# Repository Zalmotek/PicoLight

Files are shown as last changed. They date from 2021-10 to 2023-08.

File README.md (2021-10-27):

# PicoLight 🌈

✨ PicoLight is a minimalist adjustable light for low-light photography, based on the Raspberry Pi Pico.

✨ For more details check out the project documentation on [Hackaday](https://hackaday.io/project/182069-picolight-minimalist-light-for-product-shots).

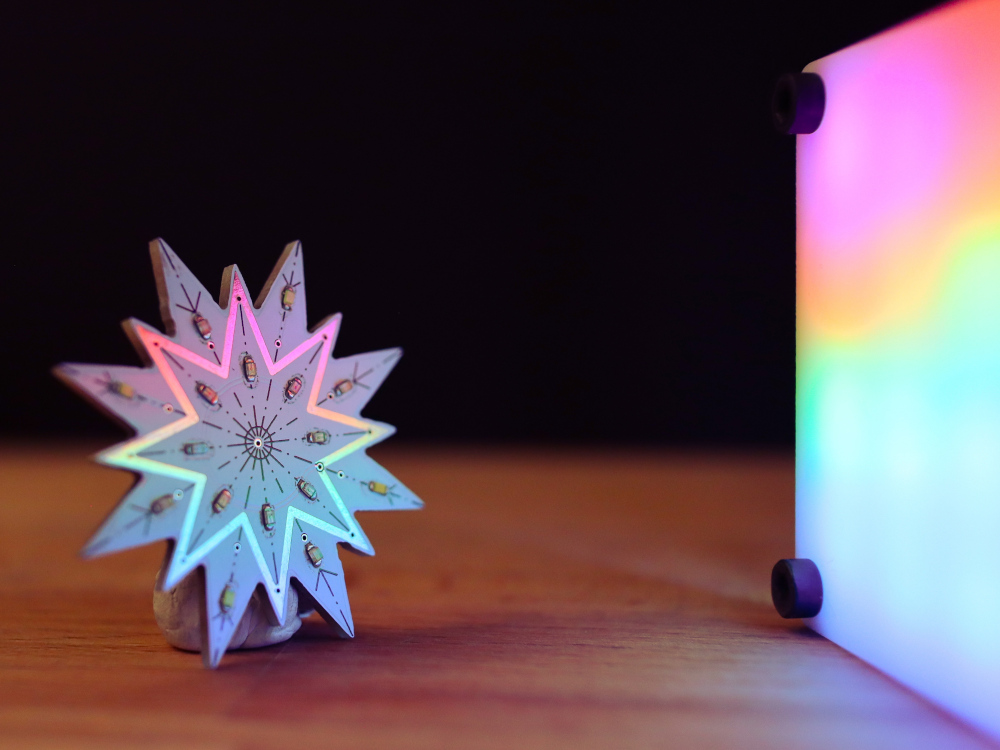
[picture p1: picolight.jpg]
PicoLight


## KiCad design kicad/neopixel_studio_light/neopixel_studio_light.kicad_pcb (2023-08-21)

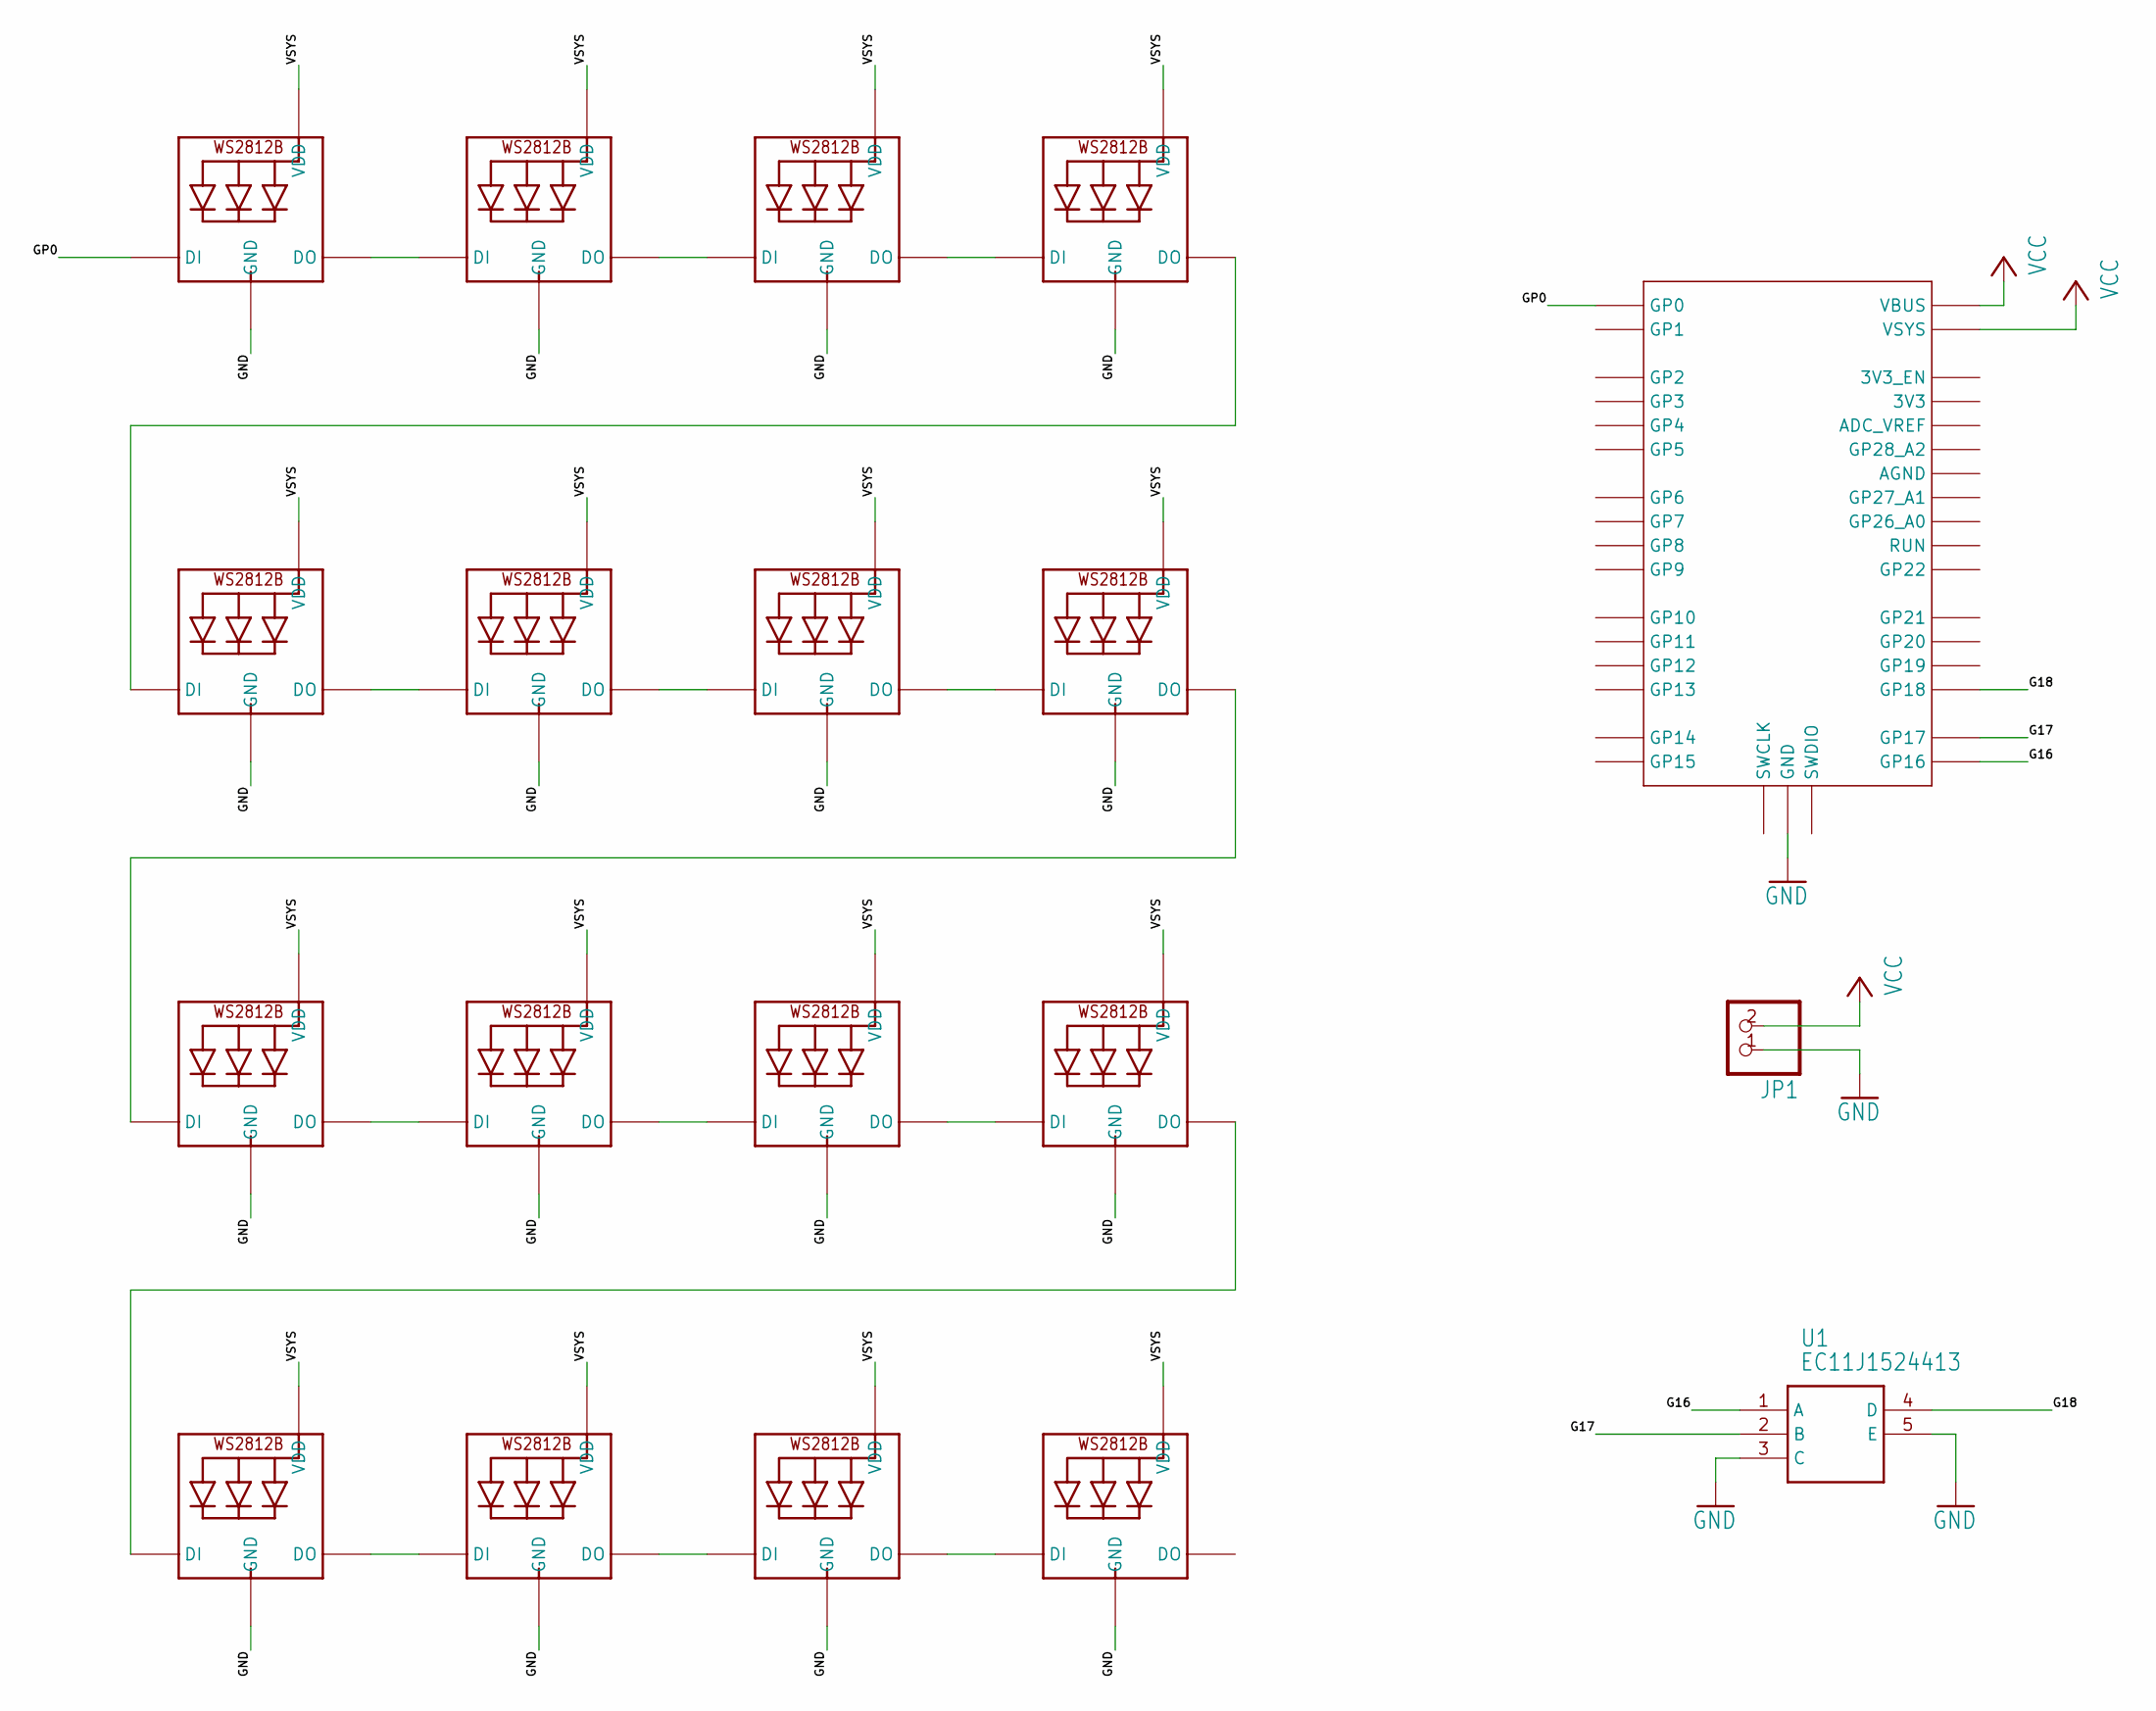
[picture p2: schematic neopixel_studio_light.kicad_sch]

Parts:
JP1: PINHD-1X2; 1X02
LED1, LED2, LED3, LED4, LED5, LED6, LED7, LED8, LED9, LED10, LED11, LED12, LED13, LED14, LED15, LED16: WS2812B5050; WS2812B
U1: EC11J1524413
U$1: RPI_PICO-SMD; RPI_PICO

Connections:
/G16: U1.1 (A), U$1.GP16
/G17: U1.2 (B), U$1.GP17
/G18: U1.4 (D), U$1.GP18
/GP0: LED1.4-DIN (DI), U$1.GP0
/VSYS: LED1.1-VDD (VDD), LED2.1-VDD (VDD), LED3.1-VDD (VDD), LED4.1-VDD (VDD), LED5.1-VDD (VDD), LED6.1-VDD (VDD), LED7.1-VDD (VDD), LED8.1-VDD (VDD), LED9.1-VDD (VDD), LED10.1-VDD (VDD), LED11.1-VDD (VDD), LED12.1-VDD (VDD), LED13.1-VDD (VDD), LED14.1-VDD (VDD), LED15.1-VDD (VDD), LED16.1-VDD (VDD)
GND: JP1.1, LED1.3-GND (GND), LED2.3-GND (GND), LED3.3-GND (GND), LED4.3-GND (GND), LED5.3-GND (GND), LED6.3-GND (GND), LED7.3-GND (GND), LED8.3-GND (GND), LED9.3-GND (GND), LED10.3-GND (GND), LED11.3-GND (GND), LED12.3-GND (GND), LED13.3-GND (GND), LED14.3-GND (GND), LED15.3-GND (GND), LED16.3-GND (GND), U1.3 (C), U1.5 (E), U$1.GND@1 (GND), U$1.GND@2 (GND), U$1.GND@3 (GND), U$1.GND@4 (GND), U$1.GND@5 (GND), U$1.GND@6 (GND), U$1.GND@7 (GND), U$1.GND@8 (GND)
unnamed: LED1.2-DOUT (DO), LED2.4-DIN (DI)
unnamed: LED2.2-DOUT (DO), LED3.4-DIN (DI)
unnamed: LED3.2-DOUT (DO), LED4.4-DIN (DI)
unnamed: LED4.2-DOUT (DO), LED5.4-DIN (DI)
unnamed: LED5.2-DOUT (DO), LED6.4-DIN (DI)
unnamed: LED6.2-DOUT (DO), LED7.4-DIN (DI)
unnamed: LED7.2-DOUT (DO), LED8.4-DIN (DI)
unnamed: LED8.2-DOUT (DO), LED9.4-DIN (DI)
unnamed: LED9.2-DOUT (DO), LED10.4-DIN (DI)
unnamed: LED10.2-DOUT (DO), LED11.4-DIN (DI)
unnamed: LED11.2-DOUT (DO), LED12.4-DIN (DI)
unnamed: LED12.2-DOUT (DO), LED13.4-DIN (DI)
unnamed: LED13.2-DOUT (DO), LED14.4-DIN (DI)
unnamed: LED14.2-DOUT (DO), LED15.4-DIN (DI)
unnamed: LED15.2-DOUT (DO), LED16.4-DIN (DI)
VCC: JP1.2, U$1.VBUS, U$1.VSYS

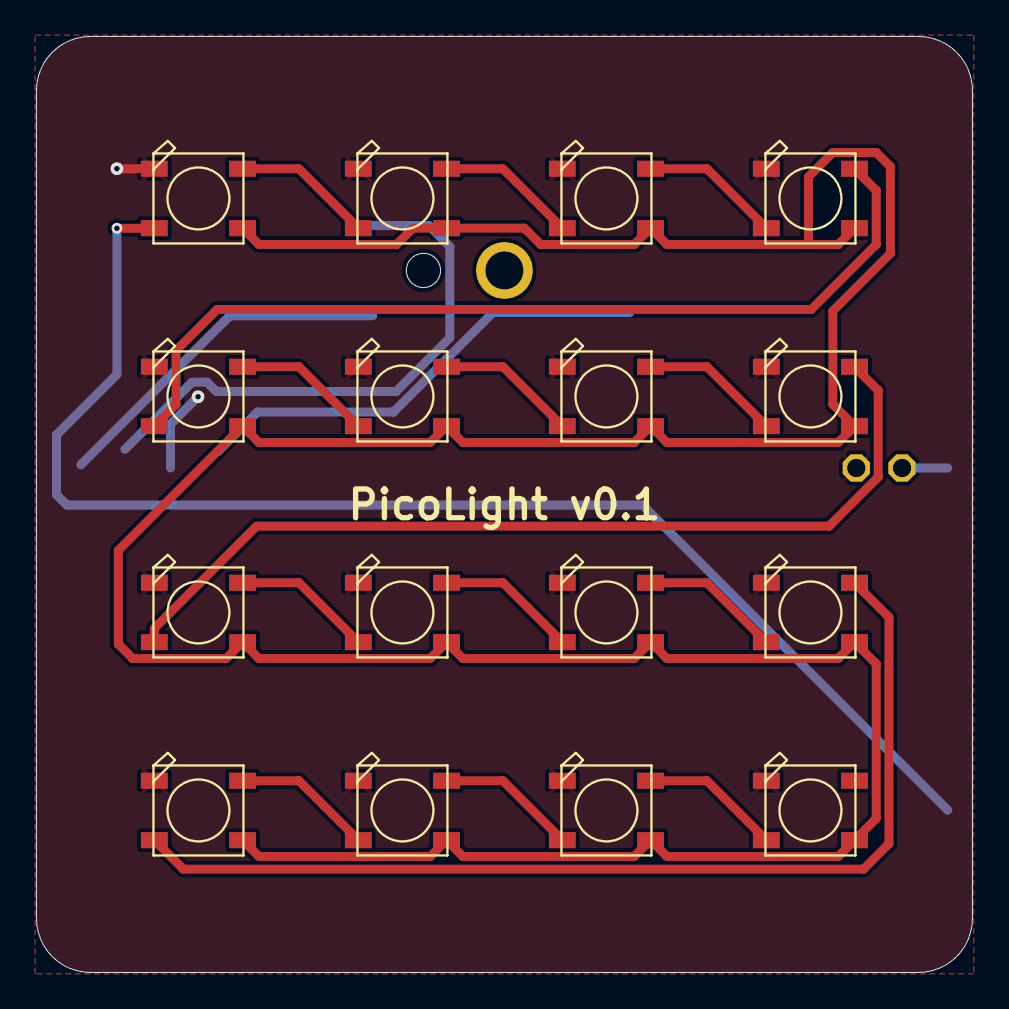
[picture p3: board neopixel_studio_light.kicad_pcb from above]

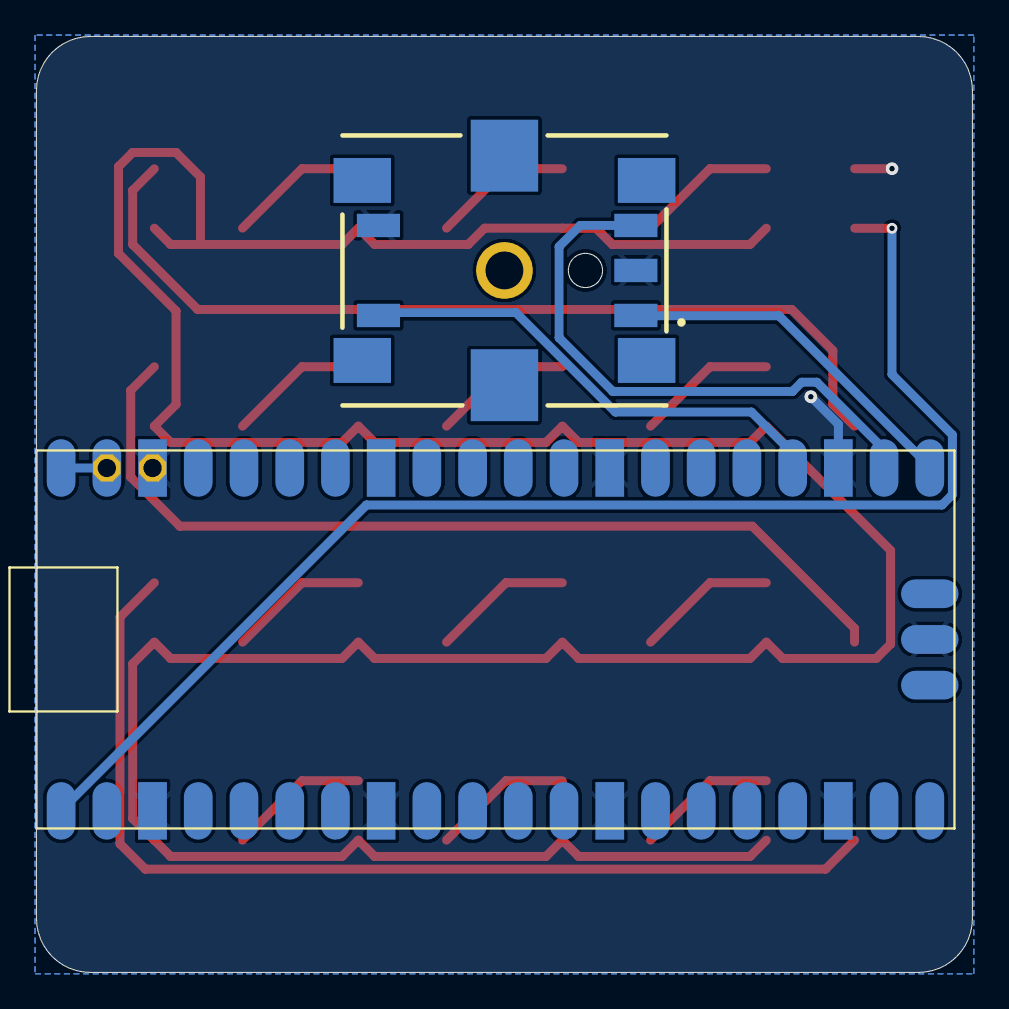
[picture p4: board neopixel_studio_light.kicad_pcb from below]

Board: 2 copper layers, 52.0 x 52.0 mm, 19 parts (2 on the bottom side), 22 nets.

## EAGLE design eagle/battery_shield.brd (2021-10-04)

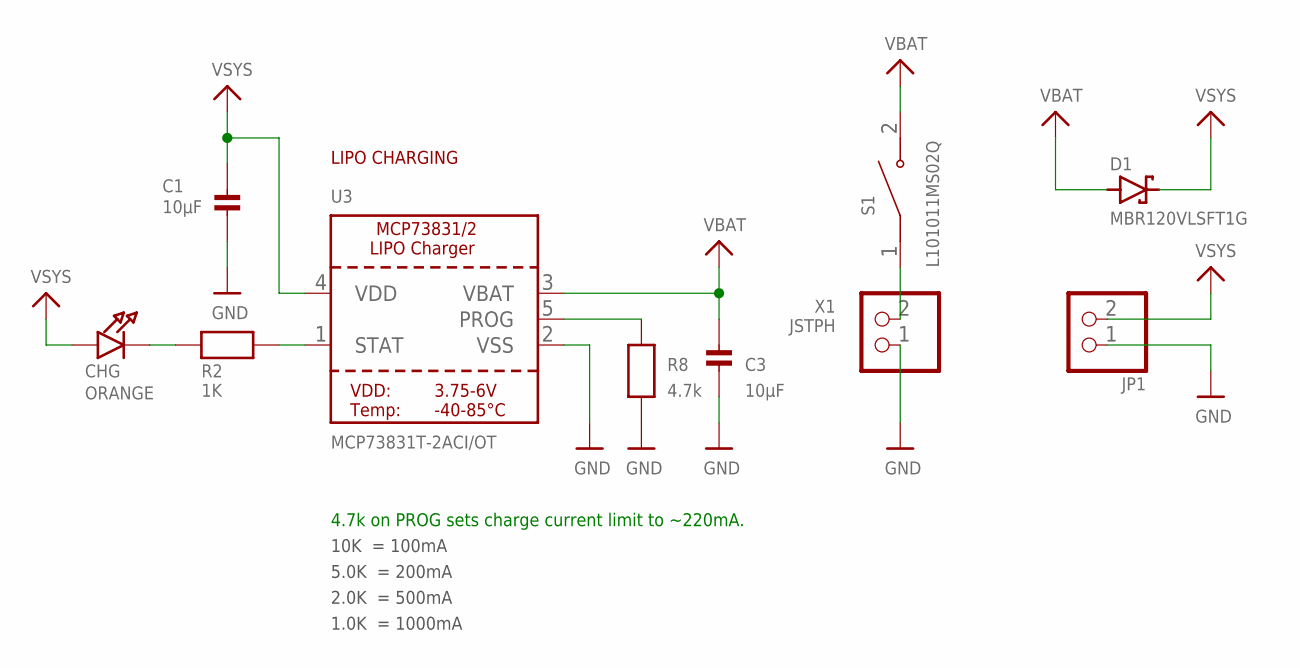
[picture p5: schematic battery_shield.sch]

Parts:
C1, C3: 10µF; 0805-NO
CHG: ORANGE; CHIPLED_0805_NOOUTLINE
D1: MBR120VLSFT1G; SOD123FL
JP1: PINHD-1X2; 1X02
R2: 1K; 0603-NO
R8: 4.7k; 0603-NO
S1: L101011MS02Q; SW_L101011MS02Q
U3: MCP73831T-2ACI/OT; SOT23-5
X1: JSTPH; JSTPH2

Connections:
GND: C1.2, C3.2, JP1.1, R8.2, U3.2 (VSS), X1.1
unnamed: CHG.C, R2.1
unnamed: S1.1, X1.2
unnamed: R2.2, U3.1 (STAT)
unnamed: R8.1, U3.5 (PROG)
VBAT: C3.1, D1.A, S1.2, U3.3 (VBAT)
VSYS: C1.1, CHG.A, D1.C, JP1.2, U3.4 (VDD)

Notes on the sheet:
10K = 100mA
5.0K = 200mA
2.0K = 500mA
1.0K = 1000mA
LIPO CHARGING
4.7k on PROG sets charge current limit to ~220mA.

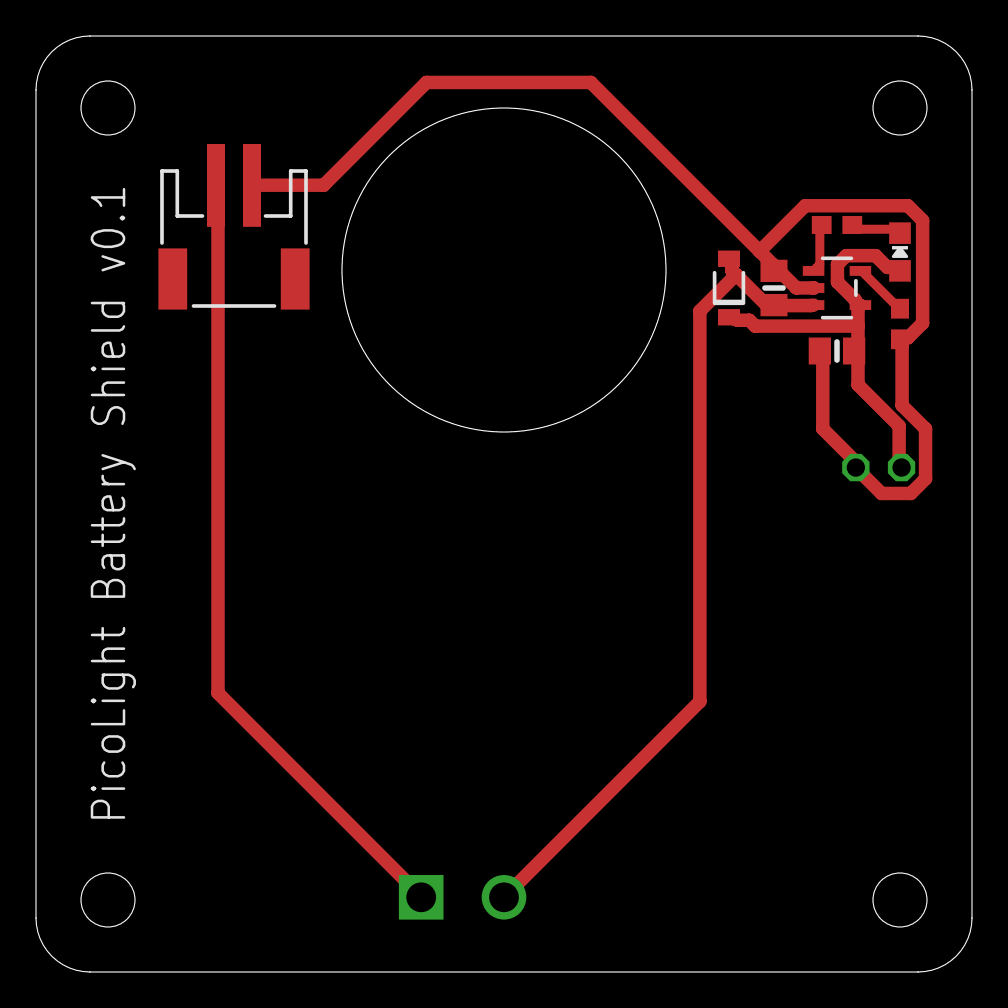
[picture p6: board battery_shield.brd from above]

Board: 2 copper layers, 52.0 x 52.0 mm, 10 parts (1 on the bottom side), 7 nets.

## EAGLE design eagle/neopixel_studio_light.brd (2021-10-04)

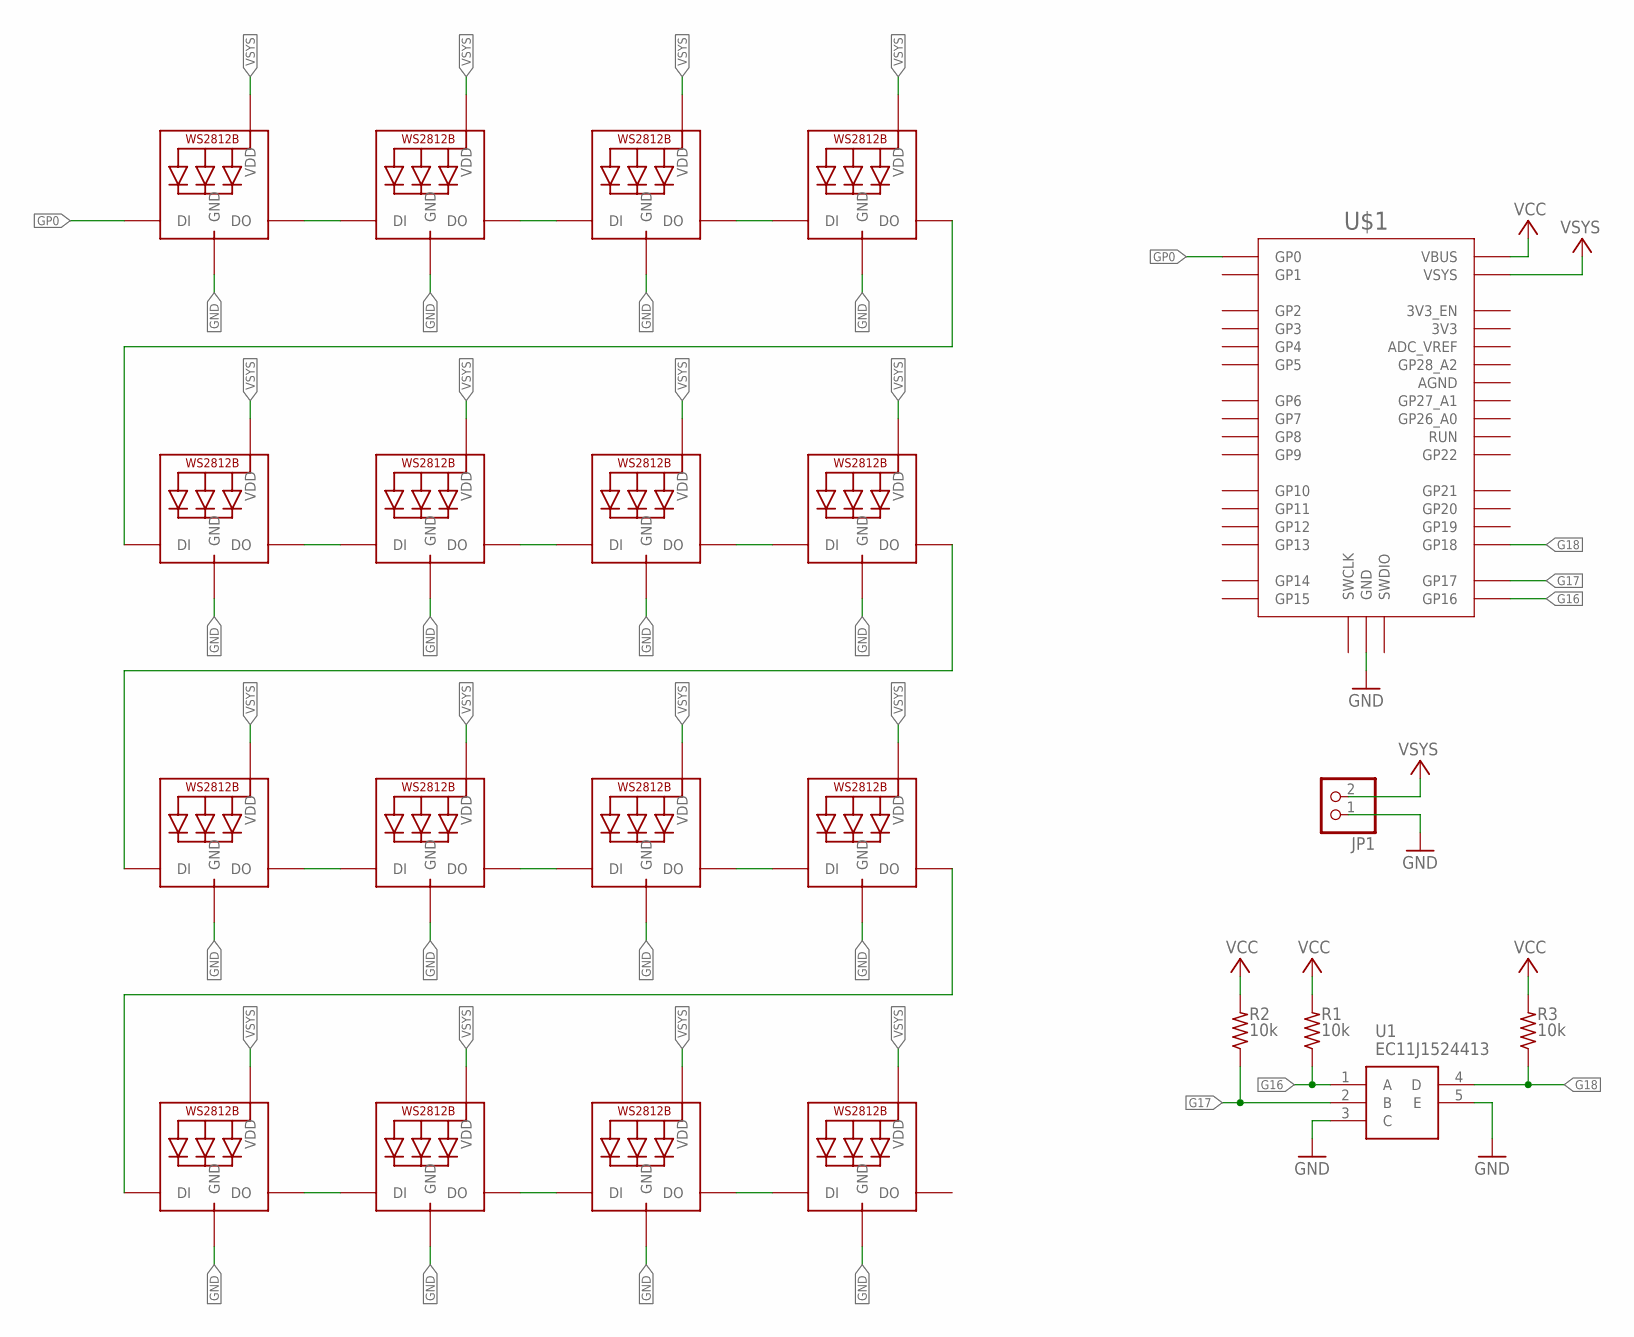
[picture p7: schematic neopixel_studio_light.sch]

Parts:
JP1: PINHD-1X2; 1X02
LED1, LED2, LED3, LED4, LED5, LED6, LED7, LED8, LED9, LED10, LED11, LED12, LED13, LED14, LED15, LED16: WS2812B5050; WS2812B
R1, R2, R3: 10k; R0603
U1: EC11J1524413
U$1: RPI_PICO-SMD; RPI_PICO

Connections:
G16: R1.1, U1.1 (A), U$1.GP16
G17: R2.1, U1.2 (B), U$1.GP17
G18: R3.1, U1.4 (D), U$1.GP18
GND: JP1.1, LED1.3-GND (GND), LED2.3-GND (GND), LED3.3-GND (GND), LED4.3-GND (GND), LED5.3-GND (GND), LED6.3-GND (GND), LED7.3-GND (GND), LED8.3-GND (GND), LED9.3-GND (GND), LED10.3-GND (GND), LED11.3-GND (GND), LED12.3-GND (GND), LED13.3-GND (GND), LED14.3-GND (GND), LED15.3-GND (GND), LED16.3-GND (GND), U1.3 (C), U1.5 (E), U$1.GND@1 (GND), U$1.GND@2 (GND), U$1.GND@3 (GND), U$1.GND@4 (GND), U$1.GND@5 (GND), U$1.GND@6 (GND), U$1.GND@7 (GND), U$1.GND@8 (GND)
GP0: LED1.4-DIN (DI), U$1.GP0
unnamed: LED1.2-DOUT (DO), LED2.4-DIN (DI)
unnamed: LED2.2-DOUT (DO), LED3.4-DIN (DI)
unnamed: LED3.2-DOUT (DO), LED4.4-DIN (DI)
unnamed: LED4.2-DOUT (DO), LED5.4-DIN (DI)
unnamed: LED5.2-DOUT (DO), LED6.4-DIN (DI)
unnamed: LED6.2-DOUT (DO), LED7.4-DIN (DI)
unnamed: LED7.2-DOUT (DO), LED8.4-DIN (DI)
unnamed: LED8.2-DOUT (DO), LED9.4-DIN (DI)
unnamed: LED12.2-DOUT (DO), LED13.4-DIN (DI)
unnamed: LED13.2-DOUT (DO), LED14.4-DIN (DI)
unnamed: LED14.2-DOUT (DO), LED15.4-DIN (DI)
unnamed: LED15.2-DOUT (DO), LED16.4-DIN (DI)
unnamed: LED9.2-DOUT (DO), LED10.4-DIN (DI)
unnamed: LED10.2-DOUT (DO), LED11.4-DIN (DI)
unnamed: LED11.2-DOUT (DO), LED12.4-DIN (DI)
VCC: R1.2, R2.2, R3.2, U$1.VBUS
VSYS: JP1.2, LED1.1-VDD (VDD), LED2.1-VDD (VDD), LED3.1-VDD (VDD), LED4.1-VDD (VDD), LED5.1-VDD (VDD), LED6.1-VDD (VDD), LED7.1-VDD (VDD), LED8.1-VDD (VDD), LED9.1-VDD (VDD), LED10.1-VDD (VDD), LED11.1-VDD (VDD), LED12.1-VDD (VDD), LED13.1-VDD (VDD), LED14.1-VDD (VDD), LED15.1-VDD (VDD), LED16.1-VDD (VDD), U$1.VSYS

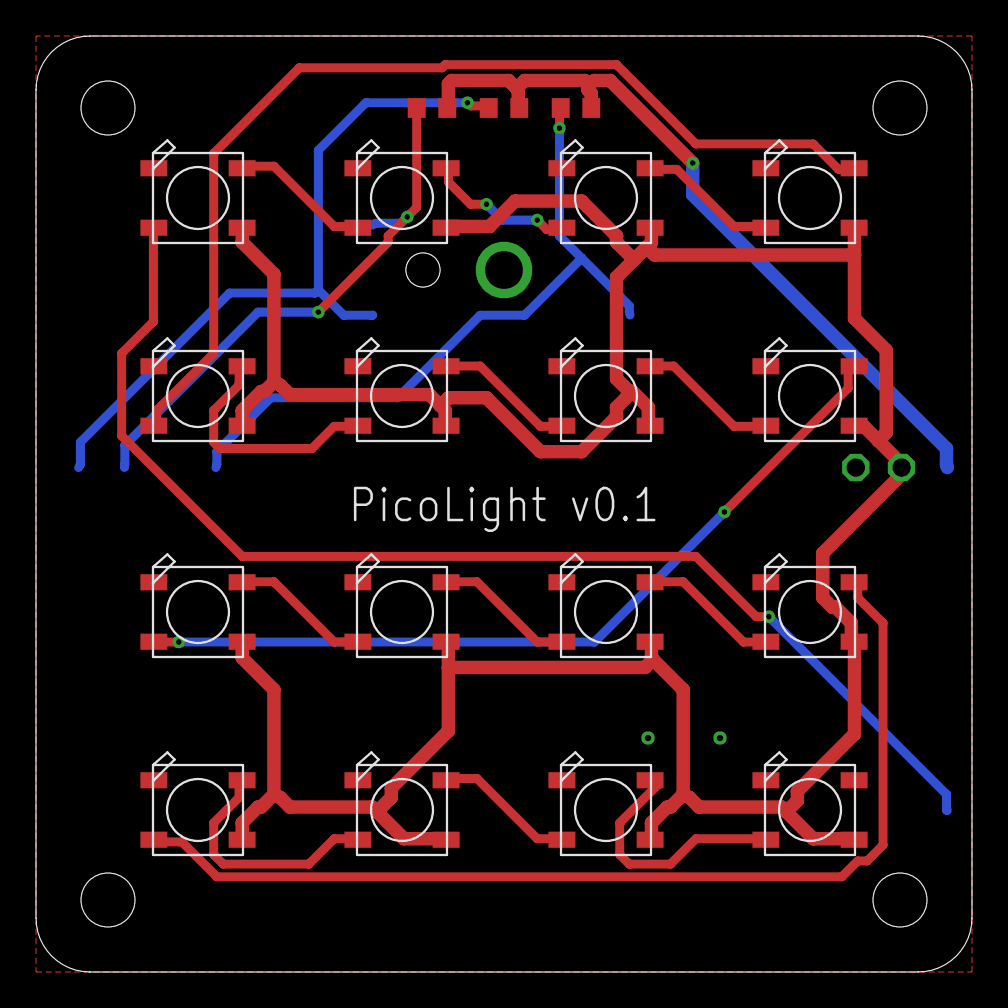
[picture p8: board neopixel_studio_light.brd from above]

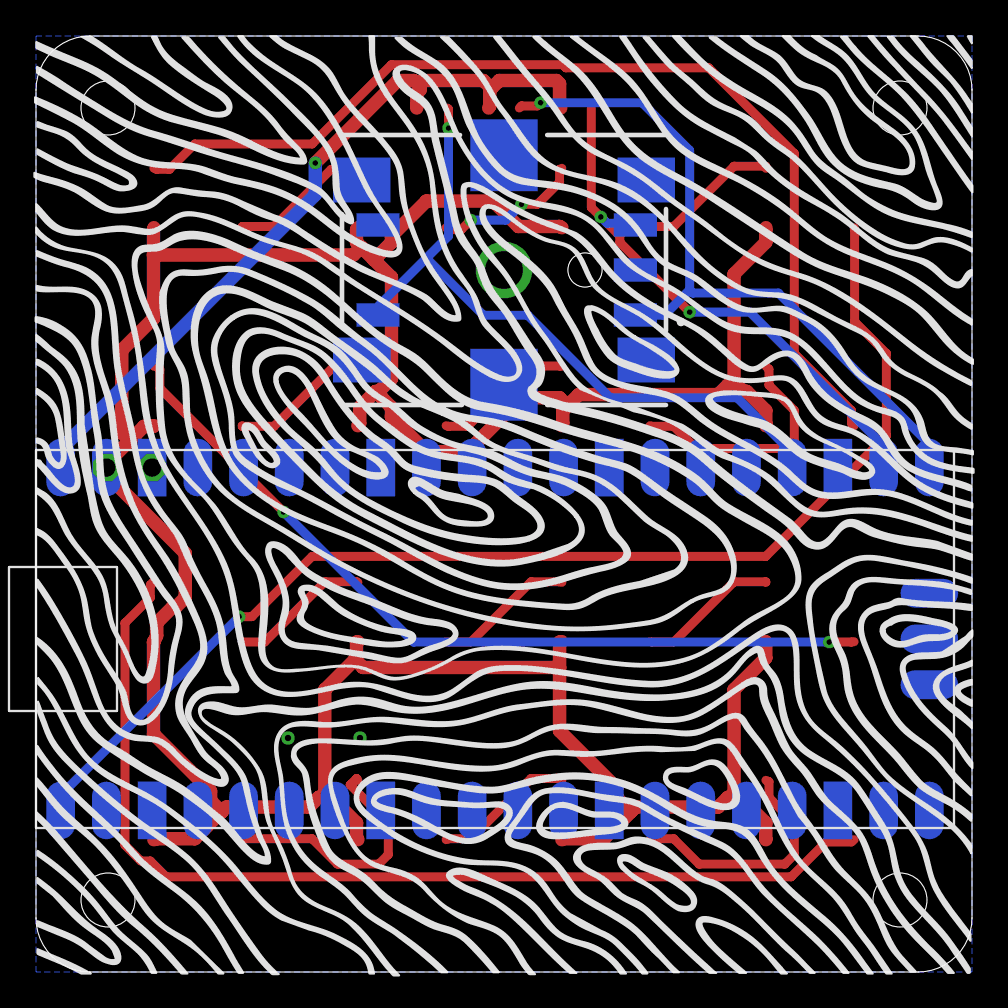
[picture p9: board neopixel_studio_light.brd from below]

Board: 2 copper layers, 52.0 x 52.0 mm, 22 parts (2 on the bottom side), 22 nets.

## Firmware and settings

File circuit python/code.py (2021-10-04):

import time
import board
import neopixel
import storage
from rotaryio import IncrementalEncoder
from digitalio import DigitalInOut, Direction, Pull

storage.remount("/", readonly=False)

# NeoPixels
num_pixels = 16
pixels = neopixel.NeoPixel(board.GP0, num_pixels)
pixels.brightness = 0.8

# Rotary Encoder
encoder = IncrementalEncoder(board.GP16, board.GP17)
button = DigitalInOut(board.GP18)
button.direction = Direction.INPUT
button.pull = Pull.UP

lastPos = 0 #None
mode = 1

redVal = 100
bluVal = 100
grnVal = 0

maxIntensity = 100
maxColourVal = 255

file = open("data.txt", "r")
data = file.read()
[colourVal, intensity] = data.split(",")
colourVal = int(colourVal)
intensity = int(intensity)
file.close()

lastPos = encoder.position

def colorwheel(color_value):
    """
    A colorwheel. ``0`` and ``255`` are red, ``85`` is green, and ``170`` is blue, with the values
    between being the rest of the rainbow.
    :param int color_value: 0-255 of color value to return
    :return: tuple of RGB values
    """
    if color_value < 0 or color_value > 255:
        return 0, 0, 0
    if color_value < 85:
        return 255 - color_value * 3, color_value * 3, 0
    if color_value < 170:
        color_value -= 85
        return 0, 255 - color_value * 3, color_value * 3
    color_value -= 170
    return color_value * 3, 0, 255 - color_value * 3

def color_chase(color, wait):
    for i in range(num_pixels):
        pixels[i] = color
        time.sleep(wait)
        pixels.show()
    time.sleep(0.1)

def rainbow_cycle(wait):
    for j in range(255):
        for i in range(num_pixels):
            rc_index = (i * 256 // num_pixels) + j
            pixels[i] = colorwheel(rc_index & 255)
            if button.value == 0:
                return None
        pixels.show()
        time.sleep(wait)
        
while True:
    if mode == 2:
        rainbow_cycle(0)
    # poll encoder position
    pos = encoder.position
    if pos != lastPos:
        if lastPos < pos:
            if mode == 1:
                if colourVal < maxColourVal:
                    colourVal = colourVal + 1
            elif mode == 0:
                if intensity < maxIntensity:
                    intensity = intensity + 1
        else:
            if mode == 1:
                if colourVal > 0:
                    colourVal = colourVal - 1
            elif mode == 0:
                if intensity > 0:
                    intensity = intensity - 1
        lastPos = pos
    
    # poll encoder button
    if button.value == 0:
        file = open("data.txt", "w")
        file.write(str(colourVal) + ",")
        file.write(str(intensity))
        file.close()
        mode = (mode + 1) % 3
        pixels.brightness = 0.2
        pixels.fill((100,100,100))
        time.sleep(0.3)
        
    if colourVal < 86:
        RGBVal = colourVal * 3
        redVal = RGBVal
        grnVal = 255 - RGBVal
        bluVal = 0
    elif colourVal < 171:
        RGBVal = (colourVal - 86) * 3
        redVal = RGBVal
        grnVal = 0
        bluVal = 255 - RGBVal
    elif colourVal < 256:
        RGBVal = (colourVal - 171) * 3
        redVal = 0
        grnVal = RGBVal
        bluVal = 255 - RGBVal
    else:
        RGBVal = (colourVal - 256) * 3
        redVal = RGBVal
        grnVal = RGBVal
        bluVal = RGBVal
        
    pixels.brightness = intensity * 0.01
    pixels.fill((redVal,grnVal,bluVal))

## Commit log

2021-10-27 added circuit python libraries + gerber files
2021-11-05 added cover laser cut file
2023-08-21 kicad files, needs mounting holes
    [neopixel_studio_light.kicad_pcb, neopixel_studio_light.kicad_sch]

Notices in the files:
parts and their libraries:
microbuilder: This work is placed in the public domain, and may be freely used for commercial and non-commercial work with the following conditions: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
